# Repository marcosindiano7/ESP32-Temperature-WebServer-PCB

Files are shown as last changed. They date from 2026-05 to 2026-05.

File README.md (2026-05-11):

# ESP32 Temperature Web Server PCB

Custom two-layer PCB designed in KiCad for an ESP32-based temperature monitoring system.  
The board measures temperature using an LM35 analog sensor and allows the measured value to be monitored through a web interface served by the ESP32 module.

This project focuses on the complete hardware development flow: schematic capture, PCB layout, manufacturing files generation, board assembly and laboratory validation.

## Project Overview

The goal of this project was to design and validate a functional printed circuit board for an IoT temperature monitoring device.

The system includes:

- ESP32 module as the main processing and communication unit
- LM35 analog temperature sensor
- USB-to-UART interface based on CH340N
- RS232 communication interface
- Communication selection through jumpers
- 5 V regulated power supply stage
- Bootloader and reset management circuitry
- Alarm LED output
- Expansion connector for additional ESP32 signals
- Two-layer PCB designed in KiCad
- SMD and through-hole component assembly
- Laboratory functional validation

## PCB Preview

### 3D Render

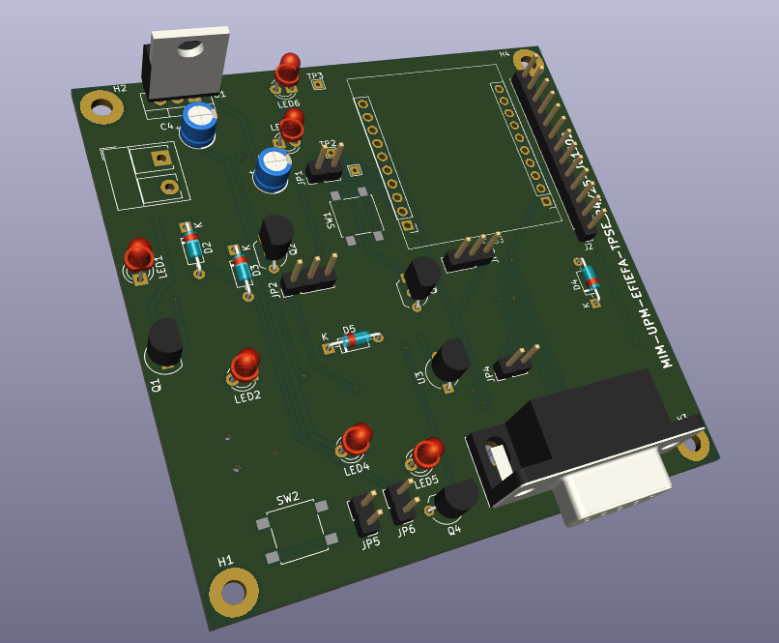
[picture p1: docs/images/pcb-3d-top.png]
PCB 3D Top Render


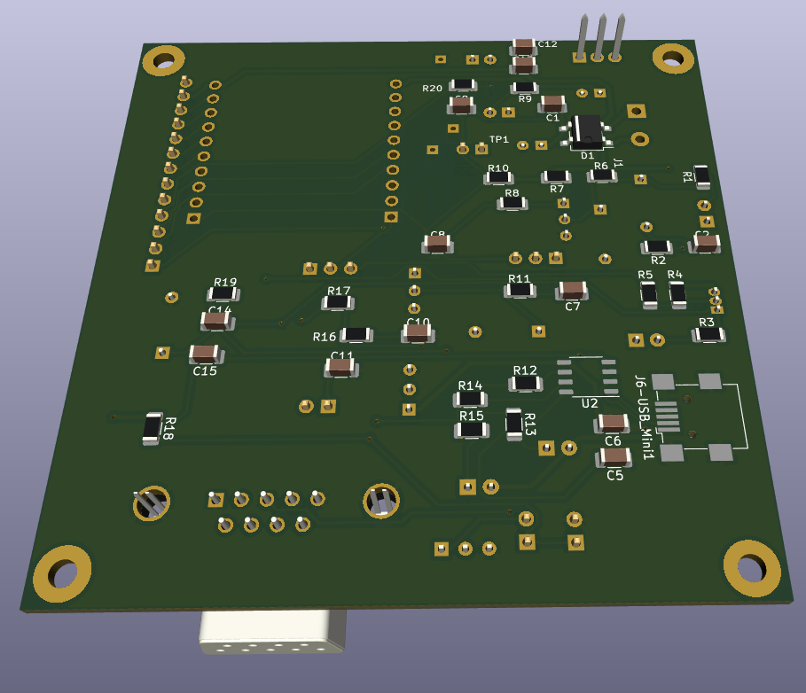
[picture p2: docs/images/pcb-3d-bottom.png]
PCB 3D Bottom Render


### PCB Layout

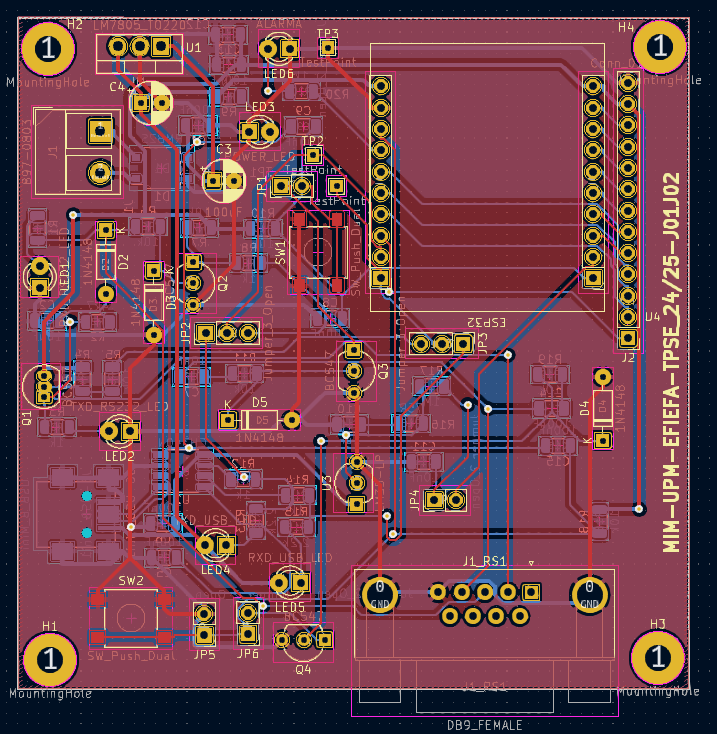
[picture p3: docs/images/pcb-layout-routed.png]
PCB Layout


### Assembled Board

Assembled PCB Top

Assembled PCB Bottom

### Web Interface

Web Interface Alert

Web Interface Normal

## Hardware Architecture

The schematic is divided into several functional blocks:

### Power Regulation

The power stage provides the regulated supply required by the system.  
It includes input filtering, a linear voltage regulator and a power indicator LED.

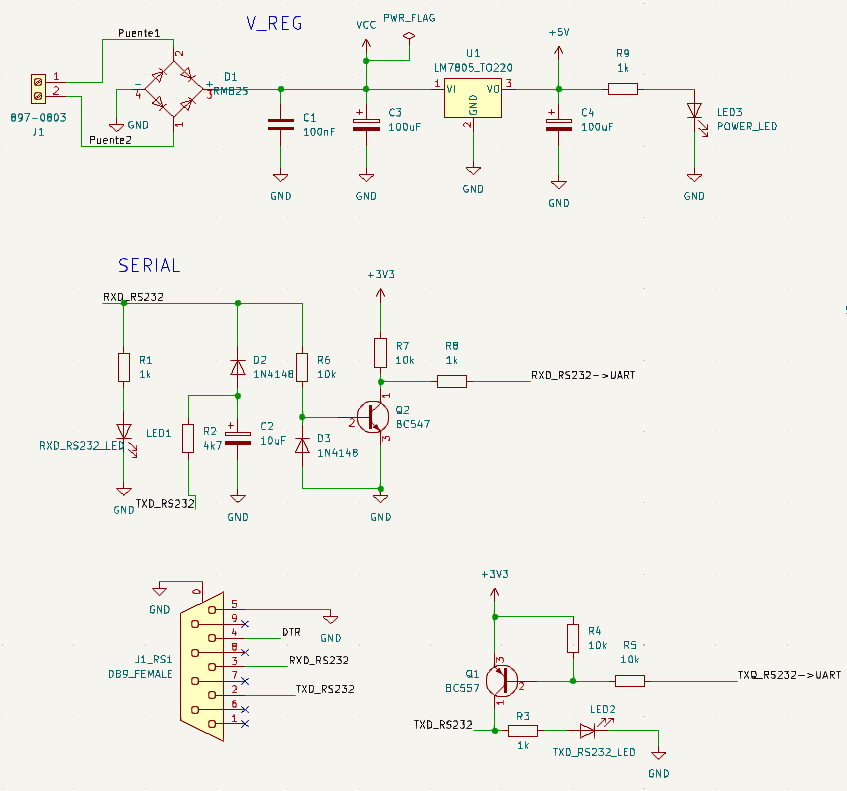
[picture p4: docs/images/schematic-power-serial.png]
Power and Serial Schematic


### ESP32 Module

The ESP32 module acts as the core of the system.  
It is connected to the temperature sensing stage, UART communication lines, boot/reset circuitry and alarm LED.

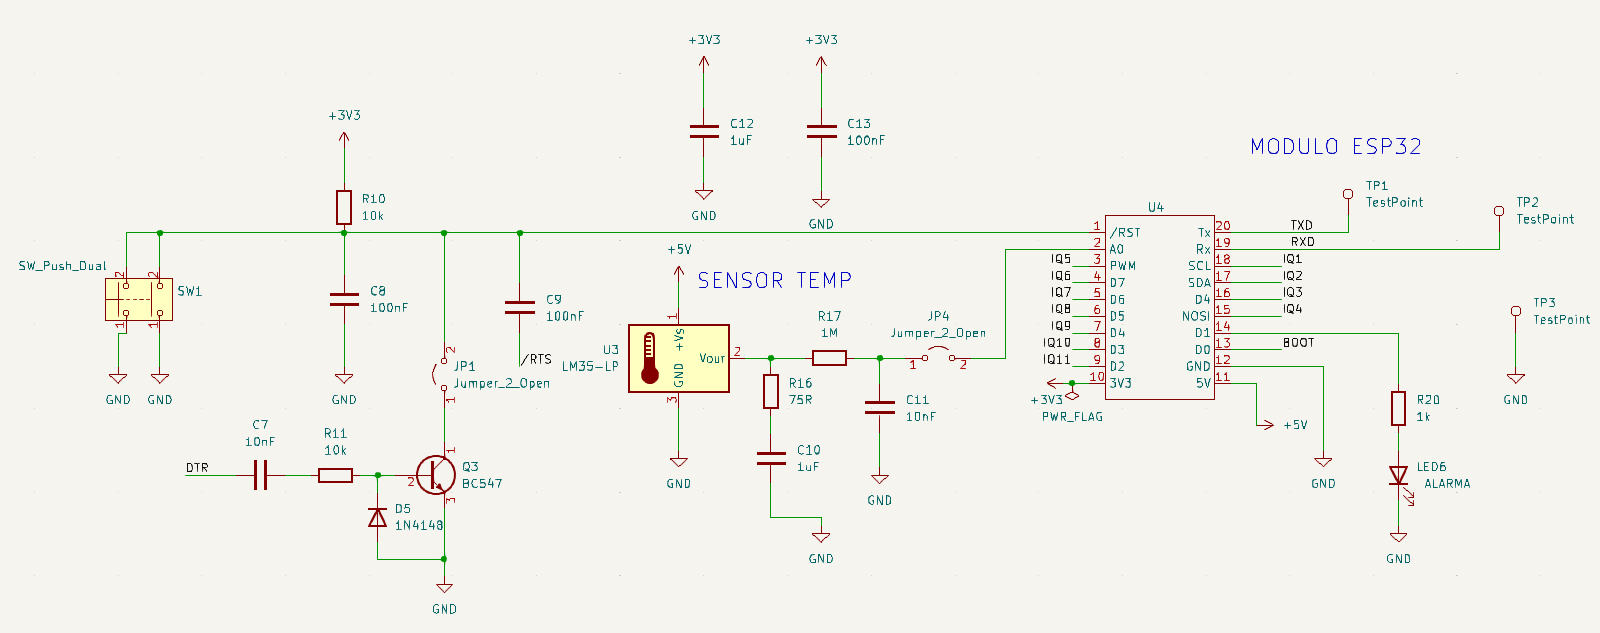
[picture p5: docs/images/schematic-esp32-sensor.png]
ESP32 and Sensor Schematic


### Temperature Sensor

The board uses an LM35 analog temperature sensor.  
Its output voltage is proportional to the measured temperature and is connected to the ESP32 analog input through a simple conditioning/filtering stage.

### USB Interface

A CH340N USB-to-UART converter is used to provide serial communication through the USB connector.

USB Schematic

### RS232 Interface

The board also includes an RS232 communication stage with level adaptation to interface with the ESP32 UART signals.

### Communication Selection

Jumpers are used to select whether the ESP32 UART lines are connected to the USB interface or to the RS232 interface.

### Bootloader and Reset Management

The design includes manual and automatic boot/reset circuitry, allowing the ESP32 to start normally or enter programming mode.

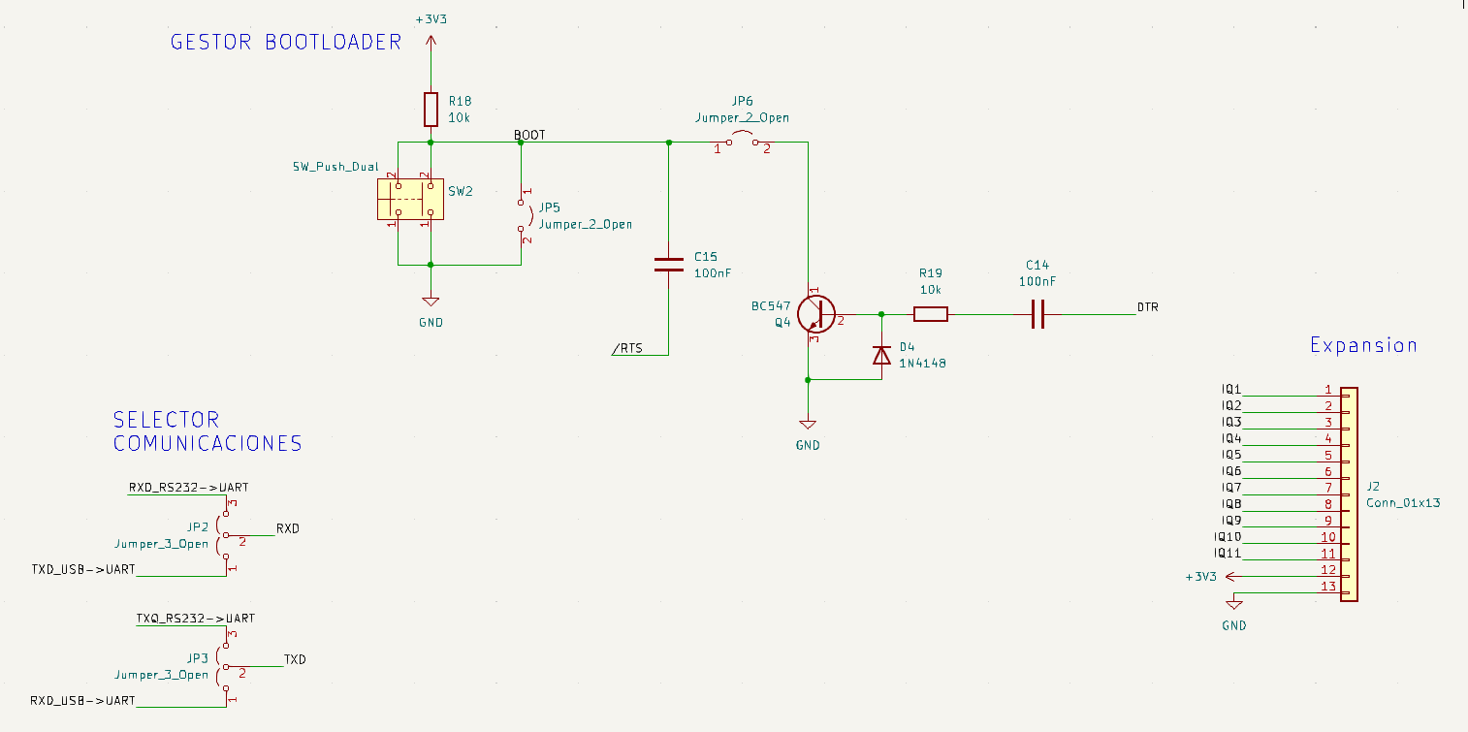
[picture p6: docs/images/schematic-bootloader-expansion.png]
Bootloader and Expansion Schematic


### Expansion Connector

An expansion connector exposes additional ESP32 pins for future extensions or external peripherals.

## Repository Structure

```text
.
├── hardware/
│   ├── kicad/              # KiCad project files
│   └── fabrication/        # Gerber and drill files
├── docs/
│   └── images/             # Schematic captures, PCB renders and photos
├── bom/                    # Bill of materials, if available
├── README.md
└── .gitignore
```

## KiCad Design

The hardware design was developed using KiCad and includes:

- Schematic capture
- Custom symbol/footprint handling
- Two-layer PCB layout
- Functional block-based component placement
- Top and bottom copper zones connected to GND
- SMD and through-hole component placement
- Mounting holes
- Silkscreen identification
- Design files ready for manufacturing

## Manufacturing Files

The `hardware/fabrication/` folder contains the production files required to manufacture the PCB:

- Top and bottom copper layers
- Top and bottom solder mask
- Top and bottom silkscreen
- Solder paste layers
- Board outline
- PTH and NPTH drill files
- Gerber job file

## Assembly

The PCB was manufactured externally and later assembled in the laboratory.  
The assembly process included both SMD and through-hole components.

Main assembled elements:

- ESP32 socket/header area
- USB connector
- DB9 RS232 connector
- Voltage regulator
- CH340N USB-to-UART converter
- LM35 temperature sensor socket
- BJTs and diode-based interface circuitry
- Jumpers and test points
- Indicator LEDs
- Mounting holes

## Validation

The assembled PCB was validated through several checks:

- Power supply verification
- 5 V regulator output measurement
- ESP32 module power-up test
- USB communication test
- RS232 communication test
- UART signal routing through jumpers
- Web server access from a mobile browser
- Temperature visualization
- Configurable threshold test
- Alarm LED activation when the temperature exceeds the configured threshold

## Functional Test

During the final test, the ESP32 web interface displayed:

- Current time
- Measured temperature
- Configurable temperature threshold
- Alarm message when the threshold was exceeded
- Button to clear the alert

Example web interface:

Web Interface Alert

## Skills Demonstrated

- PCB design with KiCad
- Schematic capture
- PCB layout and routing
- Gerber and drill file generation
- SMD soldering
- Through-hole soldering
- ESP32-based IoT hardware
- Analog sensor integration
- USB-to-UART communication
- RS232 interface design
- Boot/reset circuit integration
- Laboratory hardware validation
- Multimeter and oscilloscope-based testing
- Technical documentation

## Notes

This repository focuses on the hardware design, PCB manufacturing files and validation process.  
Firmware or software not originally developed by the author is not included.

## Author

Marcos Indiano  
Electronic Communications Engineering student  
Universidad Politécnica de Madrid

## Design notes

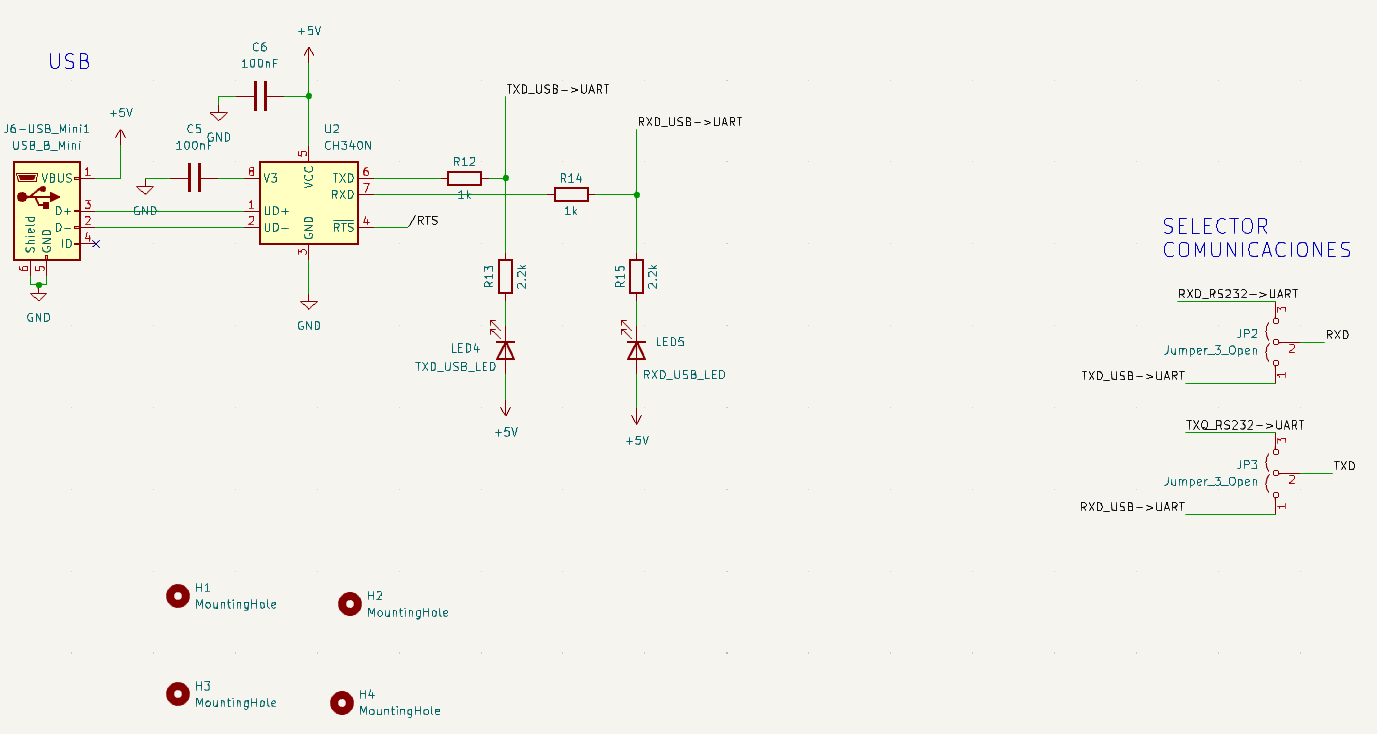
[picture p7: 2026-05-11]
docs/images/schematic-usb-comunication.png

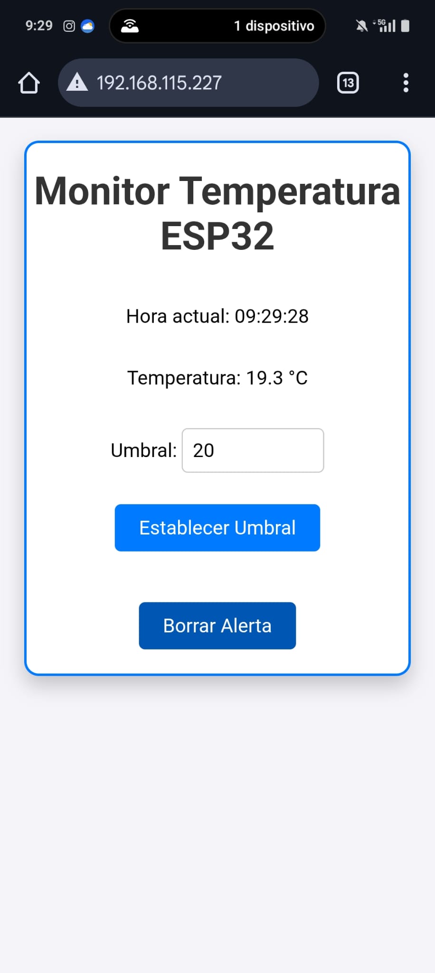
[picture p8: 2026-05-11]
docs/images/web-interface-normal.jpeg

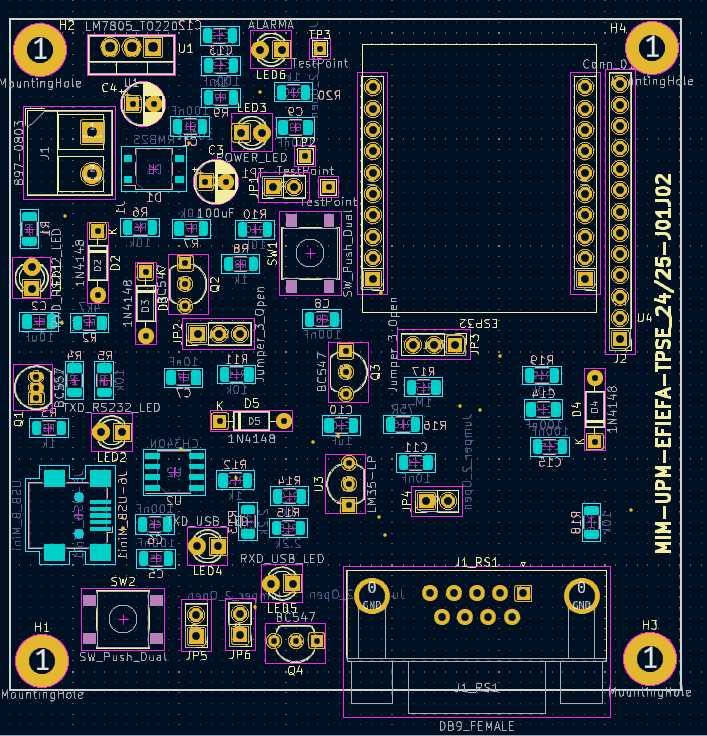
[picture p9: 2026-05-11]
docs/images/pcb-layout-unrouted.png

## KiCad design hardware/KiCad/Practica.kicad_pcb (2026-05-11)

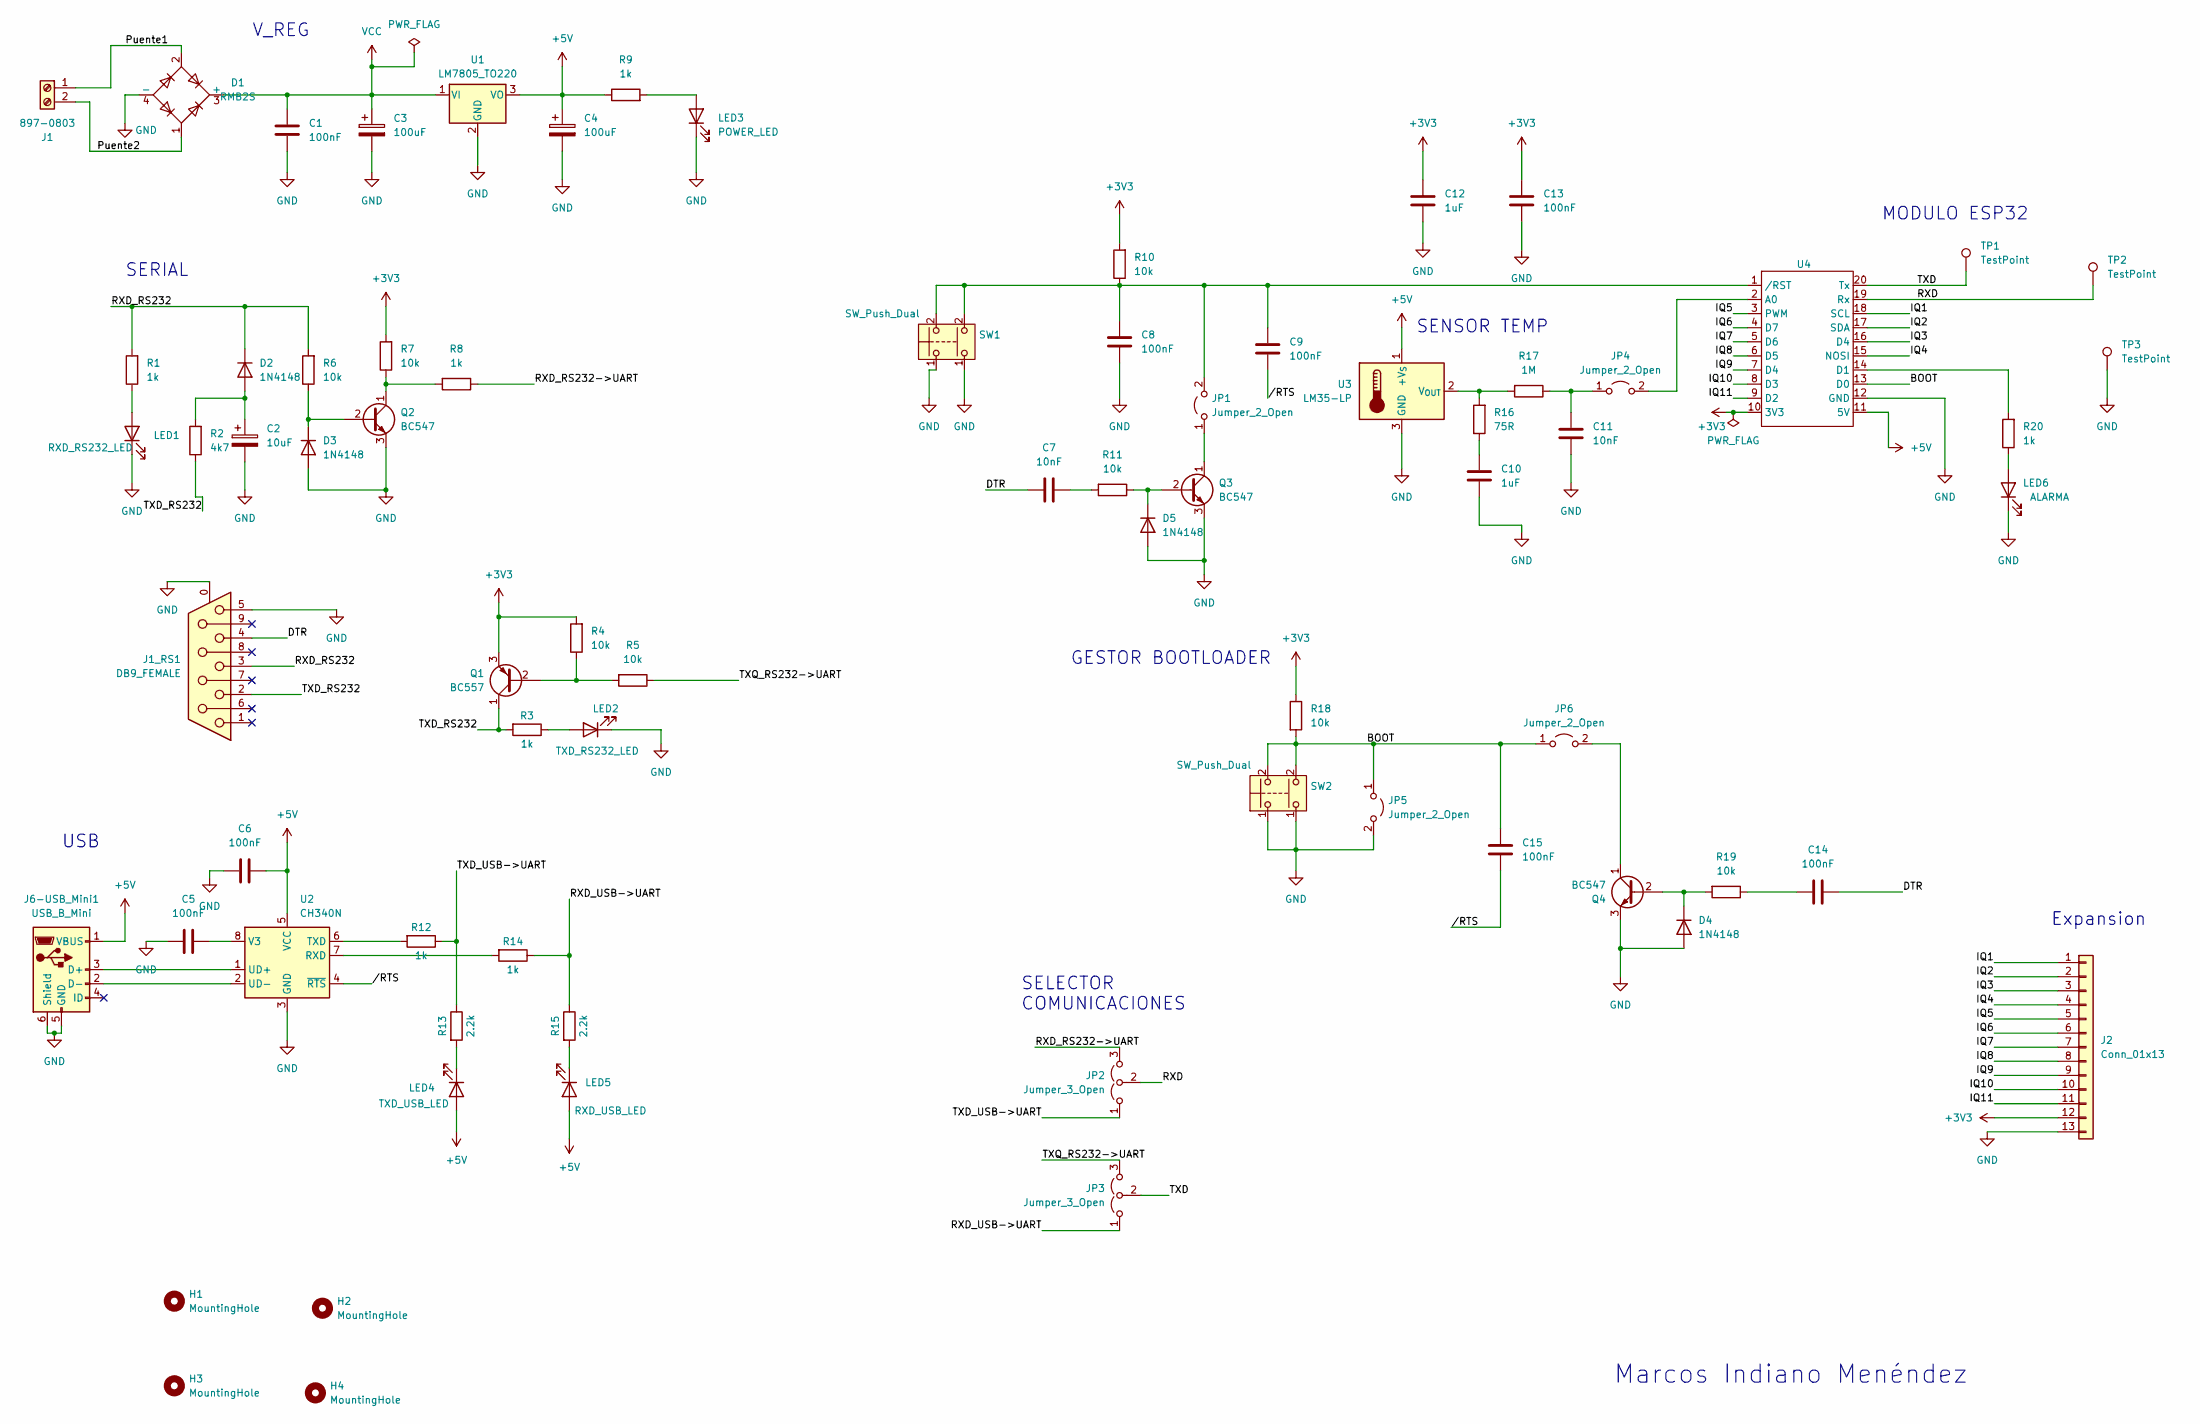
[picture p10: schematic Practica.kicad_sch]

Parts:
C1, C5, C6, C8, C9, C13, C14, C15: 100nF; C_1206_3216Metric
C2: 10uF; C_1206_3216Metric
C3, C4: 100uF; CP_Radial_D5.0mm_P2.50mm
C7, C11: 10nF; C_1206_3216Metric
C10, C12: 1uF; C_1206_3216Metric
D1: RMB2S; TO-269AA
D2, D3, D4, D5: 1N4148; D_DO-35_SOD27_P7.62mm_Horizontal
H1, H2, H3, H4: MountingHole; MountingHole_3mm_Pad
J1: 897-0803; TerminalBlock_RND_205-00276_1x02_P5.00mm_Vertical
J1_RS1: DB9_FEMALE; DSUB-9_Female_Horizontal_P2.77x2.84mm_EdgePinOffset4.94mm_H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
J2: Conn_01x13; PinHeader_1x13_P2.54mm_Vertical
J6-USB_Mini1: USB_B_Mini; USB_Mini-B_Wuerth_65100516121_Horizontal
JP1, JP4, JP5, JP6: Jumper_2_Open; PinHeader_1x02_P2.54mm_Vertical
JP2, JP3: Jumper_3_Open; PinHeader_1x03_P2.54mm_Vertical
LED1: RXD_RS232_LED; LED_D3.0mm
LED2: TXD_RS232_LED; LED_D3.0mm
LED3: POWER_LED; LED_D3.0mm
LED4: TXD_USB_LED; LED_D3.0mm
LED5: RXD_USB_LED; LED_D3.0mm
LED6: ALARMA; LED_D3.0mm
Q1: BC557; TO-92_Inline
Q2, Q3, Q4: BC547; TO-92_Inline_Wide
R1, R3, R8, R9, R12, R14, R20: 1k; R_1206_3216Metric
R2: 4k7; R_1206_3216Metric
R4, R5, R6, R7, R10, R11, R18, R19: 10k; R_1206_3216Metric
R13, R15: 2.2k; R_1206_3216Metric
R16: 75R; R_1206_3216Metric
R17: 1M; R_1206_3216Metric
SW1, SW2: SW_Push_Dual; SW_SPST_B3S-1000
TP1, TP2, TP3: TestPoint; TestPoint_THTPad_1.5x1.5mm_Drill0.7mm
U1: LM7805_TO220; TO-220-3_Vertical
U2: CH340N; SOP-8_3.9x4.9mm_P1.27mm
U3: LM35-LP; TO-92_Inline_Wide
U4: ESP32

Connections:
+3V3: C12.1, C13.1, J2.12, Q1.3 (E), R4.2, R7.2, R10.2, R18.1, U4.10 (3V3)
+5V: C4.1, C6.2, J6-USB_Mini1.1 (VBUS), LED4.2 (A), LED5.2 (A), R9.1, U1.3 (VO), U2.5 (VCC), U3.1 (+V_{S}), U4.11 (5V)
/BOOT: C15.2, JP5.1 (A), JP6.1 (A), R18.2, SW2.2 (4), U4.13 (D0)
/DTR: C7.1, C14.2, J1_RS1.4
/IQ1: J2.1, U4.18 (SCL)
/IQ2: J2.2, U4.17 (SDA)
/IQ3: J2.3, U4.16 (D4)
/IQ4: J2.4, U4.15 (NOSI)
/IQ5: J2.5, U4.3 (PWM)
/IQ6: J2.6, U4.4 (D7)
/IQ7: J2.7, U4.5 (D6)
/IQ8: J2.8, U4.6 (D5)
/IQ9: J2.9, U4.7 (D4)
/IQ10: J2.10, U4.8 (D3)
/IQ11: J2.11, U4.9 (D2)
/Puente1: D1.2, J1.1
/Puente2: D1.1, J1.2
/RXD: JP2.2 (C), TP2.1, U4.19 (Rx)
/RXD_RS232: D2.1 (K), J1_RS1.3, R1.2, R6.2
/RXD_RS232->UART: JP2.3 (B), R8.1
/RXD_USB->UART: JP3.1 (A), R14.1, R15.1
/TXD: JP3.2 (C), TP1.1, U4.20 (Tx)
/TXD_RS232: J1_RS1.2, Q1.1 (C), R2.1, R3.2
/TXD_USB->UART: JP2.1 (A), R12.1, R13.1
/TXQ_RS232->UART: JP3.3 (B), R5.1
//RTS: C9.2, C15.1, U2.4 (~RTS)
GND: C1.2, C2.2, C3.2, C4.2, C5.1, C6.1, C8.2, C10.2, C11.2, C12.2, C13.2, D1.4 (-), D3.2 (A), D4.2 (A), D5.2 (A), J1_RS1.0 (PAD), J1_RS1.5, J2.13, J6-USB_Mini1.5 (GND), J6-USB_Mini1.6 (Shield), JP5.2 (B), LED1.1 (K), LED2.1 (K), LED3.1 (K), LED6.1 (K), Q2.3 (E), Q3.3 (E), Q4.3 (E), SW1.1, SW2.1, TP3.1, U1.2 (GND), U2.3 (GND), U3.3 (GND), U4.12 (GND)
unnamed: C7.2, R11.2
unnamed: C10.1, R16.1
unnamed: C14.1, R19.1
unnamed: C2.1, D2.2 (A), R2.2
unnamed: D3.1 (K), Q2.2 (B), R6.1
unnamed: D4.1 (K), Q4.2 (B), R19.2
unnamed: D5.1 (K), Q3.2 (B), R11.1
unnamed: J6-USB_Mini1.3 (D+), U2.1 (UD+)
unnamed: J6-USB_Mini1.2 (D-), U2.2 (UD-)
unnamed: JP1.1 (A), Q3.1 (C)
unnamed: C8.1, C9.1, JP1.2 (B), R10.1, SW1.2, U4.1 (/RST)
unnamed: C11.1, JP4.1 (A), R17.1
unnamed: JP4.2 (B), U4.2 (A0)
unnamed: JP6.2 (B), Q4.1 (C)
unnamed: LED1.2 (A), R1.1
unnamed: LED2.2 (A), R3.1
unnamed: LED3.2 (A), R9.2
unnamed: LED4.1 (K), R13.2
unnamed: LED5.1 (K), R15.2
unnamed: LED6.2 (A), R20.1
unnamed: Q1.2 (B), R4.1, R5.2
unnamed: Q2.1 (C), R7.1, R8.2
unnamed: R14.2, U2.7 (RXD)
unnamed: R12.2, U2.6 (TXD)
unnamed: C5.2, U2.8 (V3)
unnamed: R16.2, R17.2, U3.2 (V_{OUT})
unnamed: R20.2, U4.14 (D1)
VCC: C1.1, C3.1, D1.3 (+), U1.1 (VI)

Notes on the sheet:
SELECTOR COMUNICACIONES
SERIAL
Marcos Indiano Menéndez
SENSOR TEMP
Expansion
USB
V_REG
MODULO ESP32
GESTOR BOOTLOADER

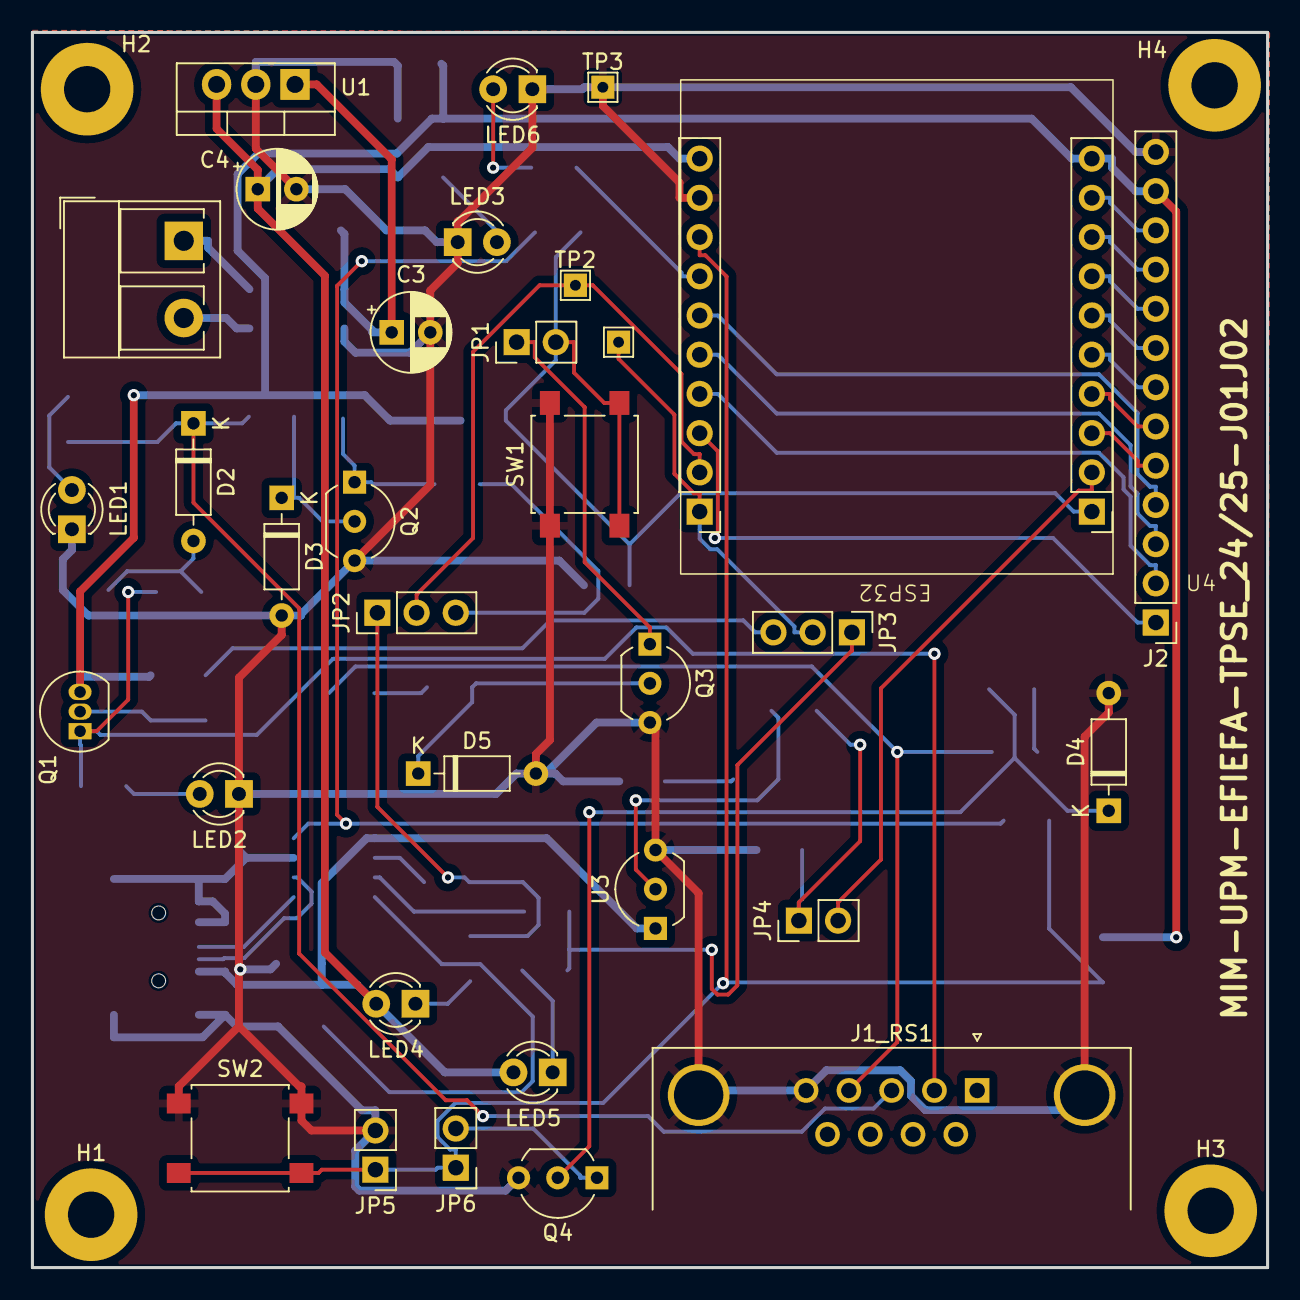
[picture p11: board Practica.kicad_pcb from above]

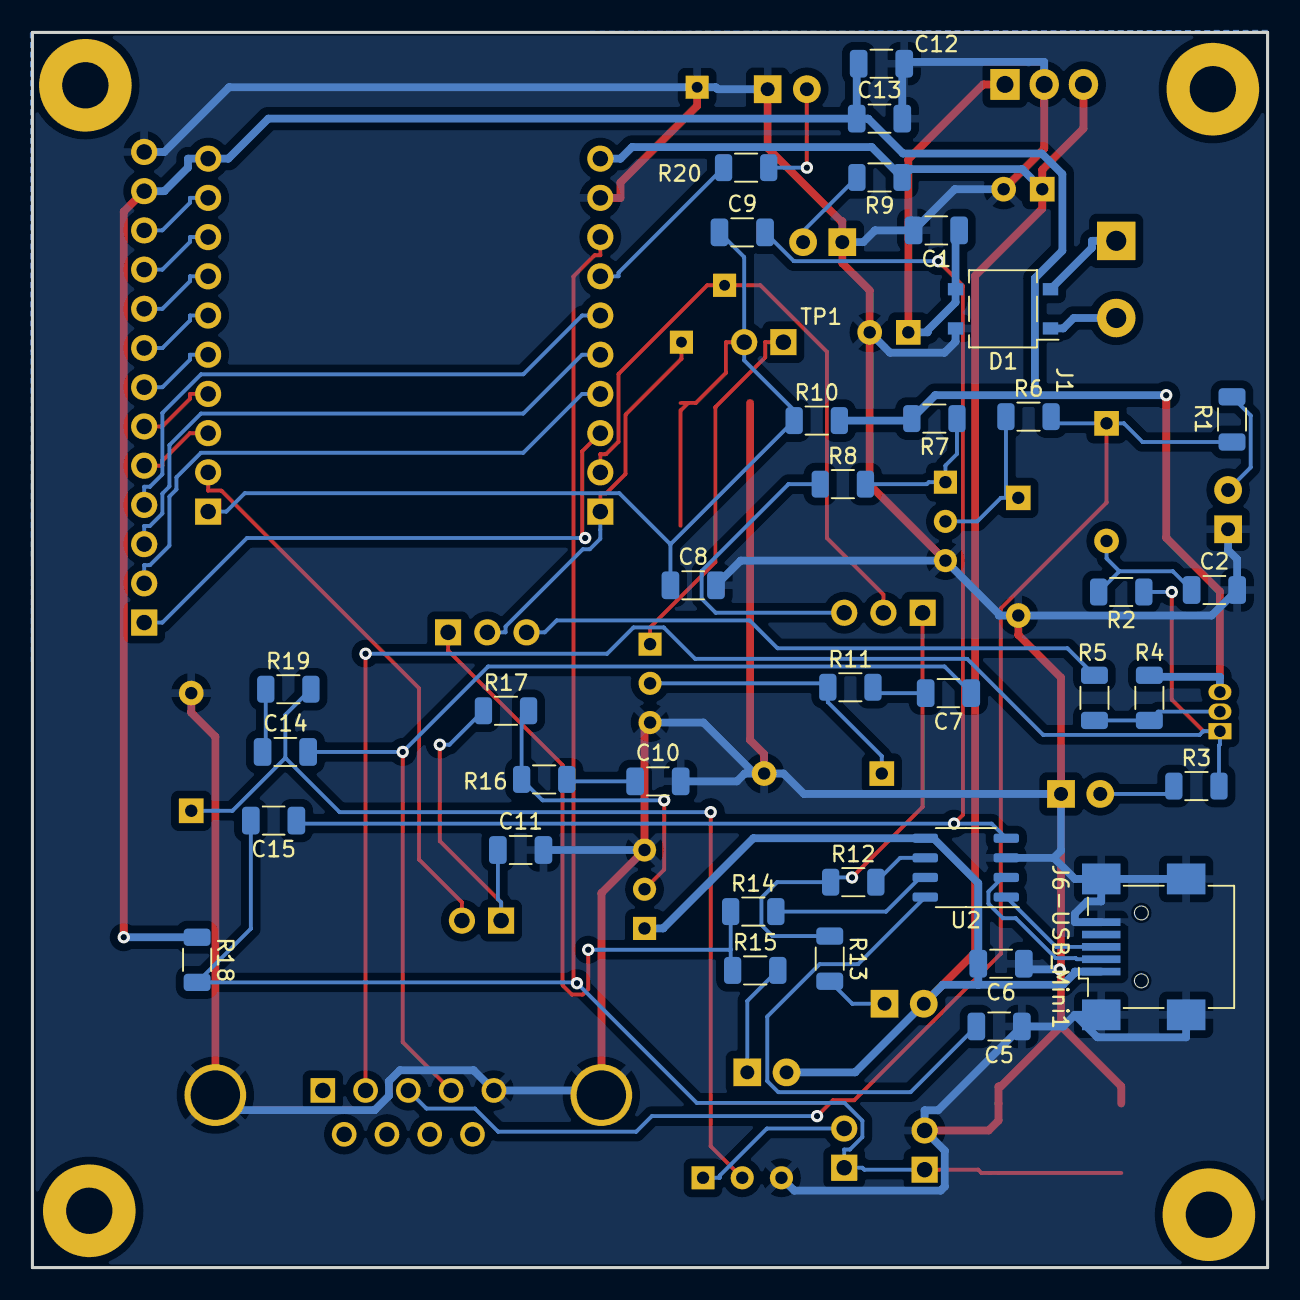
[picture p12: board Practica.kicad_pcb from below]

Board: 2 copper layers, 80.0 x 80.0 mm, 73 parts (36 on the bottom side), 55 nets.

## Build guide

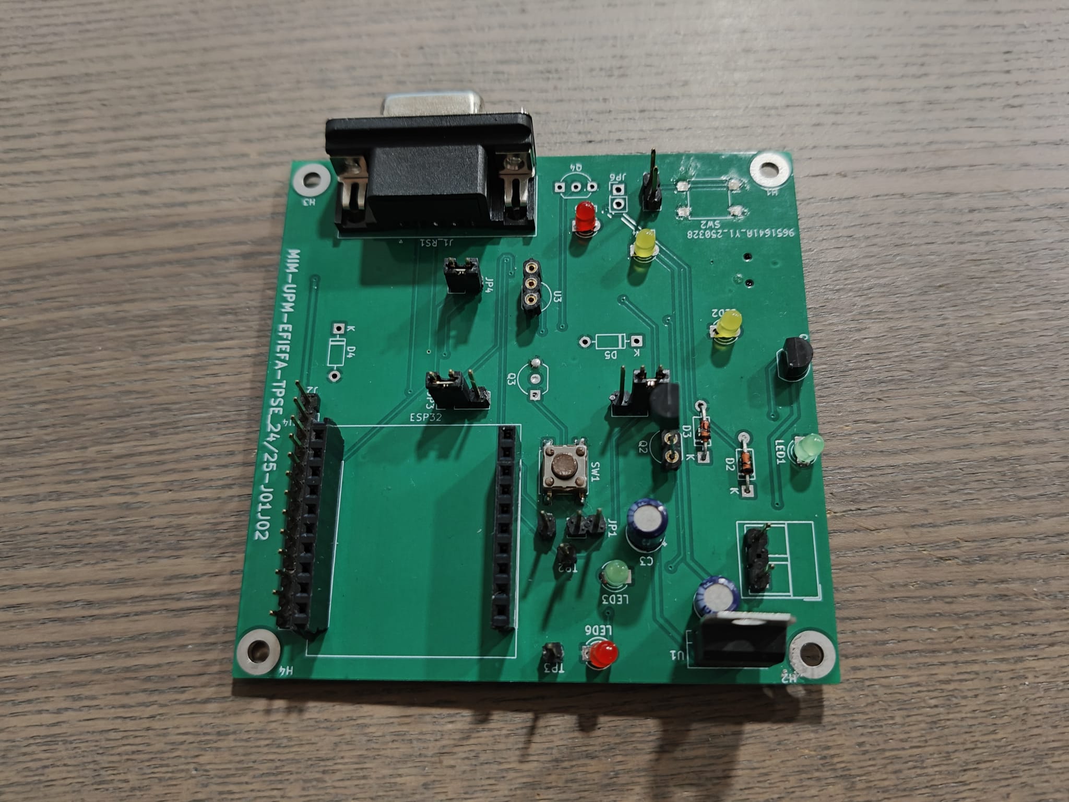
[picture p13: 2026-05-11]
docs/images/assembled-pcb-top.jpeg

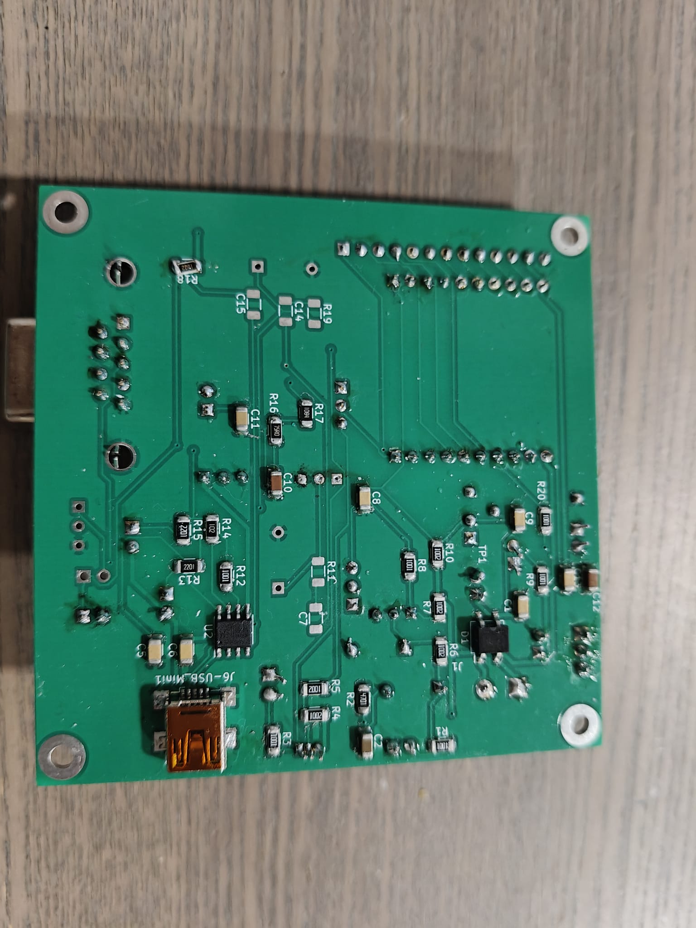
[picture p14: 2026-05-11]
docs/images/assembled-pcb-bottom.jpeg

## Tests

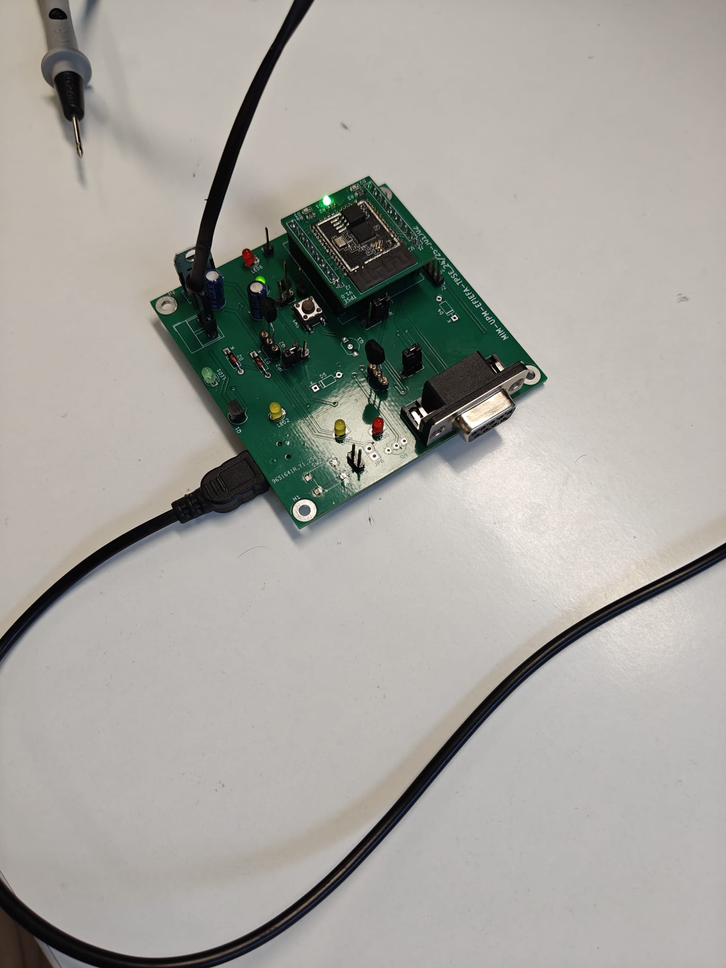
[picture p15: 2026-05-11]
docs/images/pcb-functional-test.jpeg

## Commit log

2026-05-11 ESP32-Temperature-WebServer-PCB proyect
    [Practica-B_Cu.gbr, Practica-B_Mask.gbr, Practica-B_Paste.gbr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]
2026-05-11 Add README for ESP32 Temperature Web Server PCB
    Added detailed project documentation for the ESP32 Temperature Web Server PCB, including hardware architecture, validation process, and skills demonstrated.
